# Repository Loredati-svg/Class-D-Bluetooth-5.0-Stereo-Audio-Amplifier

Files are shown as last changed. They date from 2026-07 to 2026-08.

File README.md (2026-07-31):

# 🎵 Hi-Fi Class-D Bluetooth 5.0 Stereo Audio Amplifier (2x50W)






A complete Open-Source Hardware project developed in **KiCad 9.0** for building a Hi-Fi **Class-D** stereo audio amplifier featuring an integrated **Bluetooth 5.0 HD** receiver and I2S DAC.

Designed to drive passive speakers with up to **2x50W RMS** output power into a 4Ω load powered by a 24V DC supply.

---

> 🛠️ **Project Status: Active Development**  
> This project is currently **work in progress (WIP)**. Schematics, PCB layout, and documentation are actively being refined and updated. Contributions, suggestions, and feedback are welcome!

---

## 📋 Table of Contents
- [Technical Specifications](#-technical-specifications)
- [Centralized Library Management](#-centralized-library-management)
- [PCB Design and Layout (KiCad)](#-pcb-design-and-layout-kicad)
- [Repository Structure](#-repository-structure)
- [Enclosure & 3D Printing](#-enclosure--3d-printing)
- [License](#-license)

---

## ⚡ Technical Specifications

| Parameter | Value / Specification |
| :--- | :--- |
| **Supply Voltage (DC)** | 24V DC ( 5A recommended for maximum output power) |
| **Main Amplifier IC** | Texas Instruments **TPA3116D2** (Stereo Class-D) |
| **RMS Output Power** | 2 x 50W @ 24V, 4Ω |
| **Power Efficiency** | > 90% (low thermal dissipation) |
| **Bluetooth Module** | Qualcomm **QCC3008** (Bluetooth 5.0, aptX, aptX-LL, A2DP) |
| **Audio DAC** | Texas Instruments **PCM5102A** (24-bit / 192kHz I2S) |
| **Preamp & Tone Control** | Dual Op-Amp **NE5532** / **OPA1612** (Volume, Bass, Treble) |
| **Frequency Response** | 20 Hz – 20 kHz (±0.5 dB) |
| **THD+N (Distortion)** | < 0.1% @ 1W / 1kHz (< 0.05% typical) |
| **Signal-to-Noise Ratio (SNR)** | > 102 dB |
| **Output Reconstruction Filter** | Audiophile-grade shielded LC Low-Pass Filter |
| **Built-in Protections** | Reverse Polarity (P-FET), Overvoltage, Short Circuit, Thermal Shutdown |

---

## 📚 Library Management

This project relies on a dedicated library containing all Symbols, Footprints, 3D Models, and Datasheets.

## 📐 PCB Design and Layout (KiCad)

PCB design choices in KiCad 9.0 adhere to best EMC/EMI and signal integrity practices:

1. **2-Layer Stackup (FR4 - 1.6mm - 1oz/2oz Copper):**
   * **Top Layer:** Audio signal traces, main power routing (high-current power traces > 2.5mm), and SMD components.
   * **Bottom Layer:** Continuous Ground Plane (star grounded, separated into *GND_DIGITAL*, *GND_ANALOG*, and *GND_POWER* with a single star point at the bulk input capacitor).
2. **TPA3116D2 Thermal Dissipation:**
   * Includes an array of **20+ Thermal Vias (0.3mm)** beneath the TPA3116D2 PowerPAD to conduct heat to the bottom copper plane. An extruded aluminum heatsink is attached to the top of the IC.
3. **LC Output Loops:**
   * Physical distance between the TPA3116 output pins, LC filters, and terminal blocks is minimized to prevent traces from acting as EMI radiating antennas.

## 📂 Repository Structure

```text
├── Documentation/                 # Project documentation and guides
├── Gerber/                        # Gerber, Drill, and MAP production files
├── KiCad_Project/
│   ├── Audio_Amp_v1.kicad_pro    # KiCad 8 Project File
│   ├── Audio_Amp_v1.kicad_sch    # Schematic Sheet
│   ├── Audio_Amp_v1.kicad_pcb    # PCB Layout
│   └── Audio_Amp_v1.xml          # Exported BOM
├── libs/
│   └── Kicad_Library/             # Library folder of the project
│       ├── Audio_amplifier/       # Power Amplifier ICs
│       ├── DCDC-converters/       # DC-DC converters
│       ├── Passives               # Passive components (with non standard footprint)
│       └── WIP/                   # WIP
├── Production/                    # Pick&Place (CPL) and JLCPCB BOM files
├── 3D_Print_Case/                 # STL Enclosure models for 3D printing
├── LICENSE                        # CERN-OHL-P License
└── README.md                      # Project Readme
```
---

## 🎨 Enclosure & 3D Printing

The repository includes a custom-designed, fully tailored 3D printable enclosure located in the `/3D_Print_Case` directory. It is engineered to protect the electronics while ensuring adequate passive thermal dissipation and a clean, professional look.

### 🛠️ Key Design Features
* **Front Panel:** Precise cutouts for Volume, Bass, and Treble potentiometers, Power switch, and status LEDs (Power & Bluetooth pairing).
* **Rear Panel:** Dedicated cutouts for high-quality speaker binding posts, DC barrel jack (5.5x2.5mm), and an optional SMA connector for an external Bluetooth antenna.
* **Thermal Management:** Top and bottom passive ventilation slots strategically aligned above the TPA3116D2 heatsink and LC filter inductors to prevent heat buildup.
* **Mechanical Fastening:** Designed for **M3 heat-set brass threaded inserts** (ruthex-style) embedded into internal mounting bosses for repeated assembly without wearing out printed plastic threads.

## 📜 License

This hardware project is released under the **CERN Open Hardware Licence Permissive v2 ([CERN-OHL-P v2](https://ohwr.org/cernohl))**.

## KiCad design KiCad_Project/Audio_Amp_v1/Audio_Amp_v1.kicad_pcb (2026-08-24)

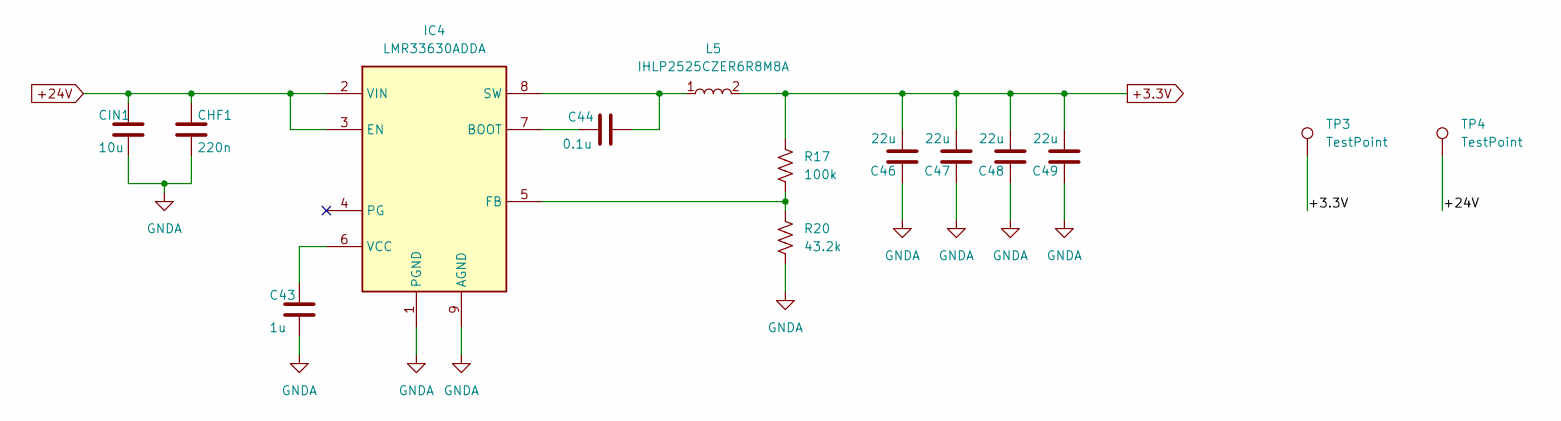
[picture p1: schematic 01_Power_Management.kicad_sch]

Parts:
C43: 1u; C_0603_1608Metric
C44: 0.1u; C_0603_1608Metric
C46, C47, C48, C49: 22u; C_0805_2012Metric
CHF1: 220n; C_0805_2012Metric
CIN1: 10u; C_1206_3216Metric
IC4: LMR33630ADDA; SOIC127P600X170-9N; Mouser Part Number 595-LMR33630BDDA
L5: IHLP2525CZER6R8M8A; INDPM6965X300N; Mouser Part Number 70-IHLP2525CZR6R8M8A
R17: 100k; R_0603_1608Metric
R20: 43.2k; R_0603_1608Metric
TP3, TP4: TestPoint; TestPoint_Pad_D2.0mm

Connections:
+3.3V: C46.2, C47.2, C48.2, C49.2, L5.2, R17.2, TP3.1 (1_1); also elsewhere on the board
+24V: CHF1.1, CIN1.1, IC4.2 (VIN), IC4.3 (EN), TP4.1 (1_1); also elsewhere on the board
GNDA: C43.2, C46.1, C47.1, C48.1, C49.1, CHF1.2, CIN1.2, IC4.1 (PGND), IC4.9 (AGND), R20.1; also elsewhere on the board
unnamed: C44.1, IC4.7 (BOOT)
unnamed: IC4.5 (FB), R17.1, R20.2
unnamed: C44.2, IC4.8 (SW), L5.1
unnamed: C43.1, IC4.6 (VCC)

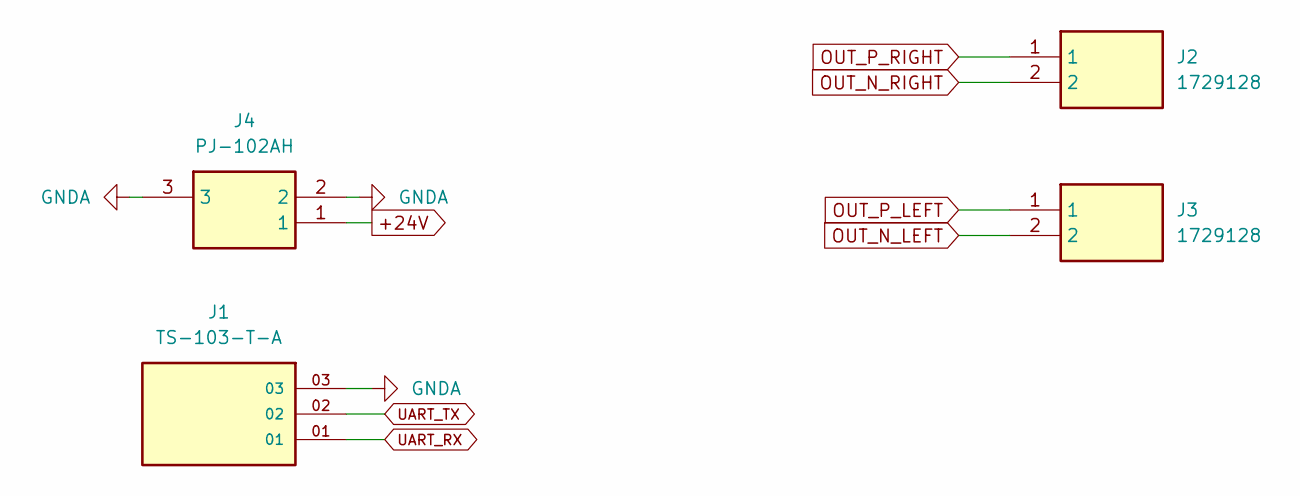
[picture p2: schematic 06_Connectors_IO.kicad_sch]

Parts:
J1: TS-103-T-A; SAMTEC_TS-103-T-A; PARTREV R
J2, J3: 1729128; Mouser Part Number 651-1729128
J4: PJ-102AH; Mouser Part Number 490-PJ-102AH

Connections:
+24V: J4.1; also elsewhere on the board
GNDA: J1.03, J4.2, J4.3; also elsewhere on the board
OUT_N_LEFT: J3.2; also elsewhere on the board
OUT_N_RIGHT: J2.2; also elsewhere on the board
OUT_P_LEFT: J3.1; also elsewhere on the board
OUT_P_RIGHT: J2.1; also elsewhere on the board
UART_RX: J1.01; also elsewhere on the board
UART_TX: J1.02; also elsewhere on the board

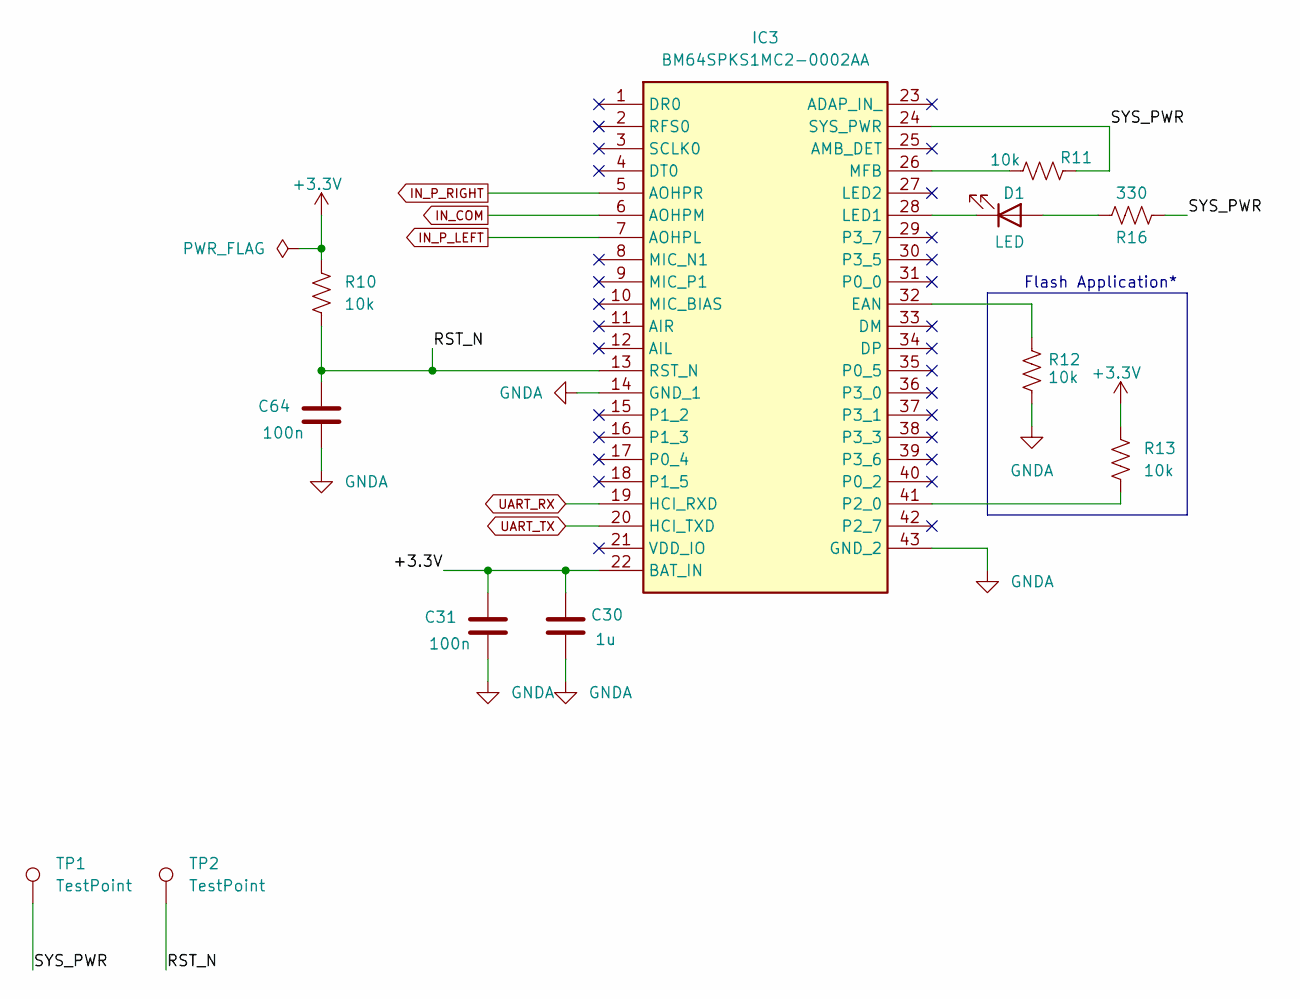
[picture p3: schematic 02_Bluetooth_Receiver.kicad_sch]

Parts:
C30: 1u; C_0603_1608Metric
C31, C64: 100n; C_0603_1608Metric
D1: LED; D_0805_2012Metric
IC3: BM64SPKS1MC2-0002AA; BM64SPKS1MC20002AA; Mouser Part Number 579-BM64SPKS1MC202AA
R10, R11, R12, R13: 10k; R_0603_1608Metric
R16: 330; R_0603_1608Metric
TP1, TP2: TestPoint; TestPoint_Pad_D2.0mm

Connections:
+3.3V: C30.1, C31.1, IC3.22 (BAT_IN), R10.1, R13.1; also elsewhere on the board
/02_Bluetooth_Receiver/RST_N: C64.1, IC3.13 (RST_N), R10.2, TP2.1 (1_1)
/02_Bluetooth_Receiver/SYS_PWR: IC3.24 (SYS_PWR), R11.2, R16.2, TP1.1 (1_1)
GNDA: C30.2, C31.2, C64.2, IC3.14 (GND_1), IC3.43 (GND_2), R12.1; also elsewhere on the board
IN_COM: IC3.6 (AOHPM); also elsewhere on the board
IN_P_LEFT: IC3.7 (AOHPL); also elsewhere on the board
IN_P_RIGHT: IC3.5 (AOHPR); also elsewhere on the board
unnamed: D1.2 (A), R16.1
unnamed: D1.1 (K), IC3.28 (LED1)
unnamed: IC3.32 (EAN), R12.2
unnamed: IC3.26 (MFB), R11.1
unnamed: IC3.41 (P2_0), R13.2
UART_RX: IC3.19 (HCI_RXD); also elsewhere on the board
UART_TX: IC3.20 (HCI_TXD); also elsewhere on the board

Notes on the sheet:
Flash Application*

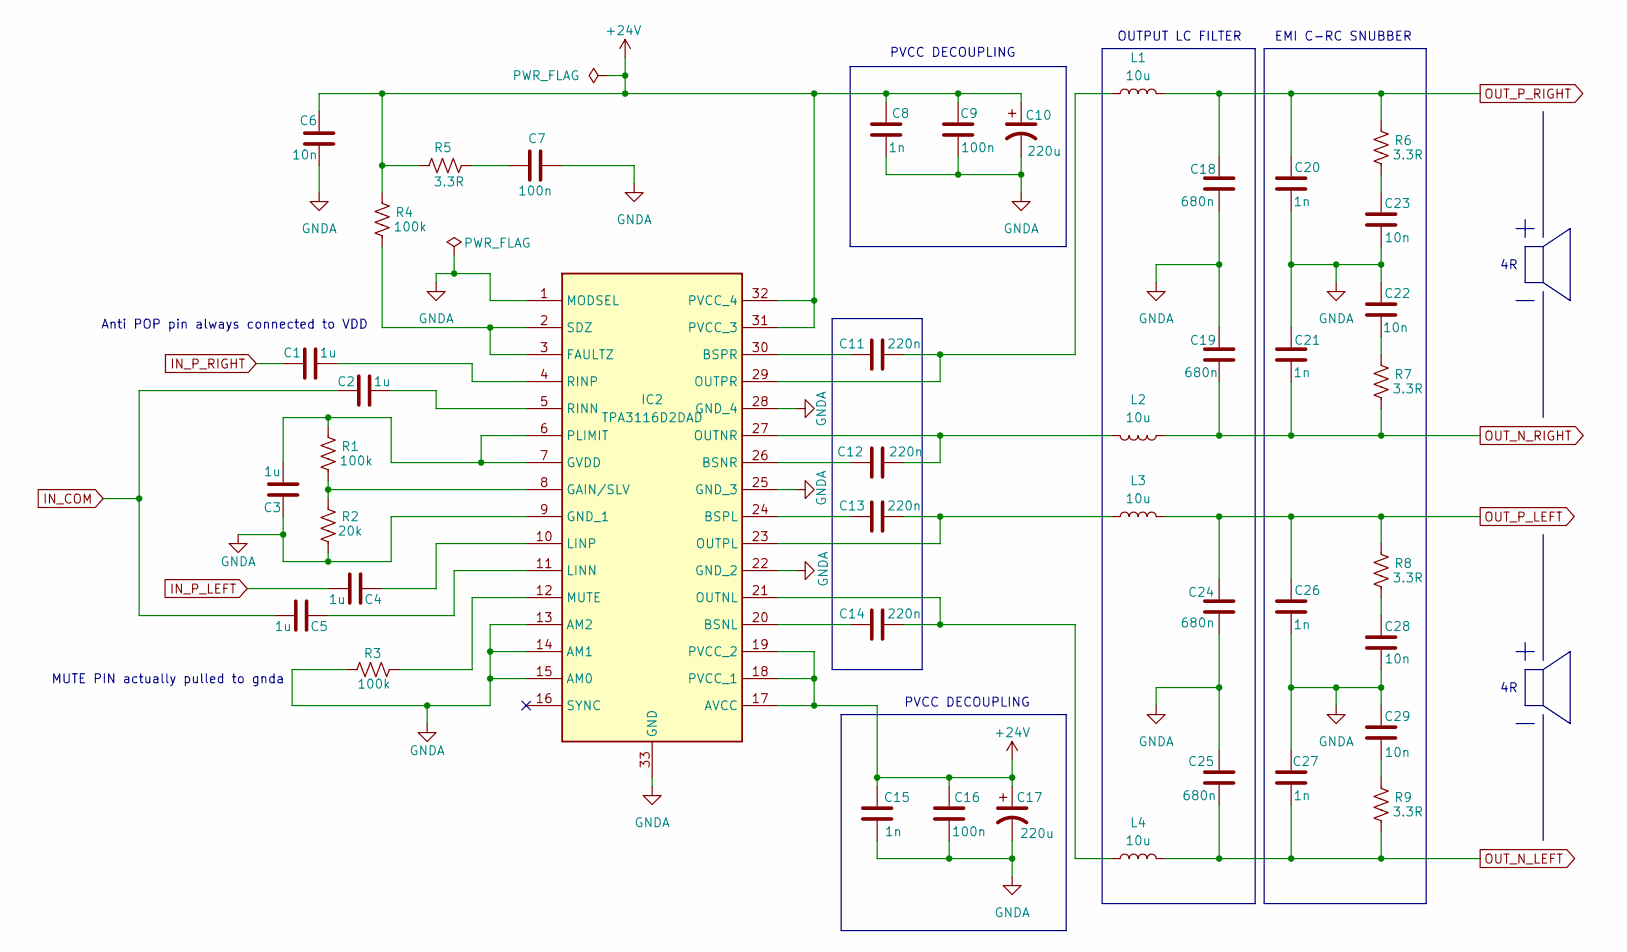
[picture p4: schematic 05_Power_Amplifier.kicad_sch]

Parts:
C1, C2, C3, C4, C5: 1u; C_0603_1608Metric
C6, C22, C23, C28, C29: 10n; C_0603_1608Metric
C7: 100n; C_0603_1608Metric
C8, C15: 1n; C_0805_2012Metric
C9, C16: 100n; C_0805_2012Metric
C10, C17: 220u; EEHZT1E561UV
C11, C12, C13, C14: 220n; C_0805_2012Metric
C18, C19, C24, C25: 680n; C_1206_3216Metric
C20, C21, C26, C27: 1n; C_0603_1608Metric
IC2: TPA3116D2DAD; SOP65P810X120-32N; Mouser Part Number 595-TPA3116D2DAD
L1, L2, L3, L4: 10u; INDPM8479X720N
R1, R3, R4: 100k; R_0603_1608Metric
R2: 20k; R_0603_1608Metric
R5, R6, R7, R8, R9: 3.3R; R_1206_3216Metric

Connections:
+24V: C6.2, C8.1, C9.1, C10.1, C15.1, C16.1, C17.1, IC2.17 (AVCC), IC2.18 (PVCC_1), IC2.19 (PVCC_2), IC2.31 (PVCC_3), IC2.32 (PVCC_4), R4.1, R5.1; also elsewhere on the board
GNDA: C3.1, C6.1, C7.1, C8.2, C9.2, C10.2, C15.2, C16.2, C17.2, C18.2, C19.1, C20.2, C21.1, C22.1, C23.2, C24.2, C25.1, C26.2, C27.1, C28.2, C29.1, IC2.1 (MODSEL), IC2.9 (GND_1), IC2.13 (AM2), IC2.14 (AM1), IC2.15 (AM0), IC2.22 (GND_2), IC2.25 (GND_3), IC2.28 (GND_4), IC2.33 (GND), R2.2, R3.1; also elsewhere on the board
IN_COM: C2.1, C5.2; also elsewhere on the board
IN_P_LEFT: C4.2; also elsewhere on the board
IN_P_RIGHT: C1.1; also elsewhere on the board
unnamed: C7.2, R5.2
unnamed: C22.2, R7.1
unnamed: C23.1, R6.2
unnamed: C28.1, R8.2
unnamed: C29.2, R9.1
unnamed: C14.1, IC2.20 (BSNL)
unnamed: C12.1, IC2.26 (BSNR)
unnamed: C13.1, IC2.24 (BSPL)
unnamed: C11.1, IC2.30 (BSPR)
unnamed: IC2.2 (SDZ), IC2.3 (FAULTZ), R4.2
unnamed: IC2.8 (GAIN/SLV), R1.2, R2.1
unnamed: C3.2, IC2.6 (PLIMIT), IC2.7 (GVDD), R1.1
unnamed: C5.1, IC2.11 (LINN)
unnamed: C4.1, IC2.10 (LINP)
unnamed: IC2.12 (MUTE), R3.2
unnamed: C14.2, IC2.21 (OUTNL), L4.1
unnamed: C12.2, IC2.27 (OUTNR), L2.2
unnamed: C13.2, IC2.23 (OUTPL), L3.1
unnamed: C11.2, IC2.29 (OUTPR), L1.1
unnamed: C2.2, IC2.5 (RINN)
unnamed: C1.2, IC2.4 (RINP)
OUT_N_LEFT: C25.2, C27.2, L4.2, R9.2; also elsewhere on the board
OUT_N_RIGHT: C19.2, C21.2, L2.1, R7.2; also elsewhere on the board
OUT_P_LEFT: C24.1, C26.1, L3.2, R8.1; also elsewhere on the board
OUT_P_RIGHT: C18.1, C20.1, L1.2, R6.1; also elsewhere on the board

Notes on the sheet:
EMI C-RC SNUBBER
OUTPUT LC FILTER
Anti POP pin always connected to VDD
PVCC DECOUPLING
MUTE PIN actually pulled to gnda

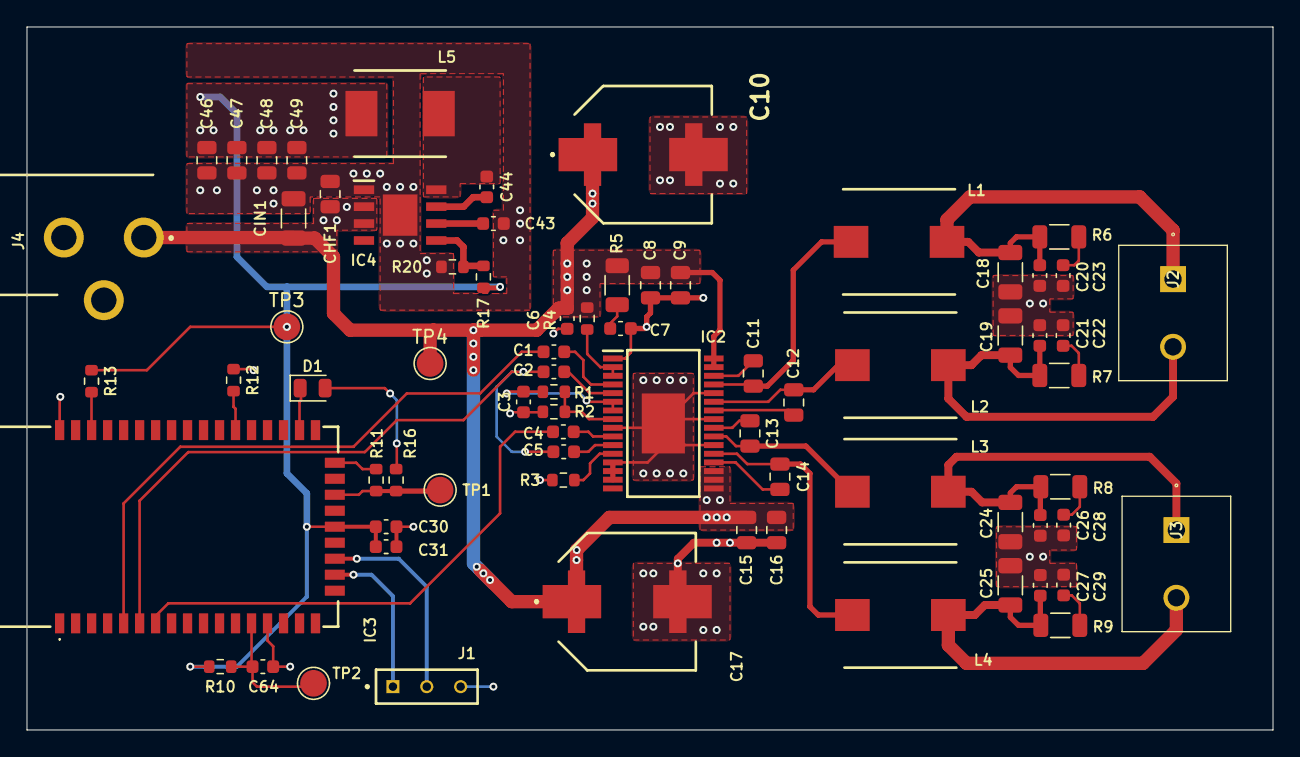
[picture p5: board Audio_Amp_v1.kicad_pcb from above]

Board: 2 copper layers, 93.5 x 52.8 mm, 73 parts (0 on the bottom side), 44 nets.

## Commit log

2026-07-30 Add folder structure and Kicad_Library submodule
2026-07-30 Add schematic sheets and hierarchical structure
    [01_Power_Management.kicad_sch, 02_Bluetooth_Receiver.kicad_sch, 03_Audio_DAC.kicad_sch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]
2026-07-30 Add power amplifier schematic, custom library, and initial components
    [01_Power_Management.kicad_sch, 05_Power_Amplifier.kicad_sch]
2026-07-30 Convert Kicad_Library to regular folder and add custom libraries
2026-07-31 Added some passive components and updated the Power amplifier schematic with footprints
    [05_Power_Amplifier.kicad_sch, Audio_Amp_v1.kicad_sch]
2026-08-01 Updated Power management section, Bluetooth receiver and connectors. Added some components footprints and 3D.
    [01_Power_Management.kicad_sch, 02_Bluetooth_Receiver.kicad_sch, 03_Audio_DAC.kicad_sch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]
2026-08-02 Added USB_C schematic and updated the DAC
    [03_Audio_DAC.kicad_sch, 06_Connectors_IO.kicad_sch]
2026-08-06 Remove KiCad .history from tracking, add to gitignore
    [01_Power_Management.kicad_sch, 02_Bluetooth_Receiver.kicad_sch, 03_Audio_DAC.kicad_sch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]
2026-08-06 Add KiCad history folder
2026-08-19 Finished Schematic and started Layout
    [01_Power_Management.kicad_sch, 02_Bluetooth_Receiver.kicad_sch, 05_Power_Amplifier.kicad_sch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]
2026-08-19 Continued Layout
    [01_Power_Management.kicad_sch, Audio_Amp_v1.kicad_pcb]
2026-08-24 Layout Updated, finished routing
    [05_Power_Amplifier.kicad_sch, 06_Connectors_IO.kicad_sch, Audio_Amp_v1.kicad_pcb]
